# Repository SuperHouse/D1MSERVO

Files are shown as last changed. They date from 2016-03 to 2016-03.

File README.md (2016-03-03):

Servo Shield for the WeMos D1 Mini
==================================

Copyright 2016 SuperHouse Automation Pty Ltd  
SuperHouse site:  www.superhouse.tv  
SuperHouse email: info@superhouse.tv  

A 16-channel servo controller shield for the [WeMos D1 Mini][1] 
and other compatible boards based on the same header format.

Features:

 * 16 PWM output channels at 3.3V.
 * I2C interface with pull-up resistors.
 * Configurable I2C address to allow stacking. Default address 0x40.
 * PCA9685 PWM controller IC.
 * SCL: D1. SDA: D2.
 * External power terminals for powering servos at 6V.
 * Power jumper to link D1 Mini 5V rail to servo power.
 * OE (active low Output Enable) broken out for manual connection if required.
 * Power LED to show when servo power is available.

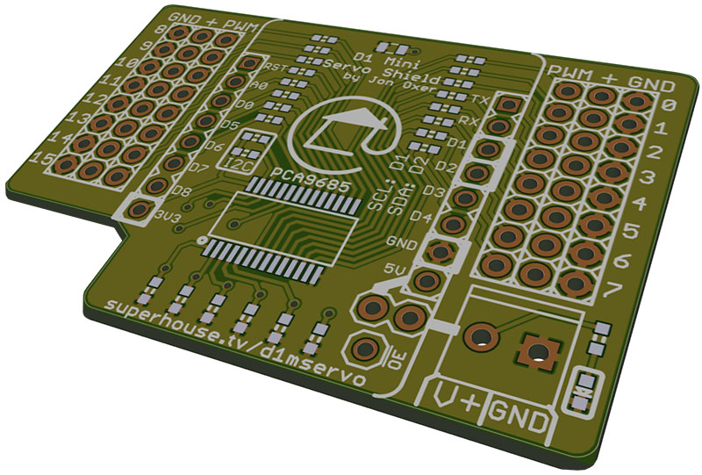
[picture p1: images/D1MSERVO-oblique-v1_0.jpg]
Oblique view


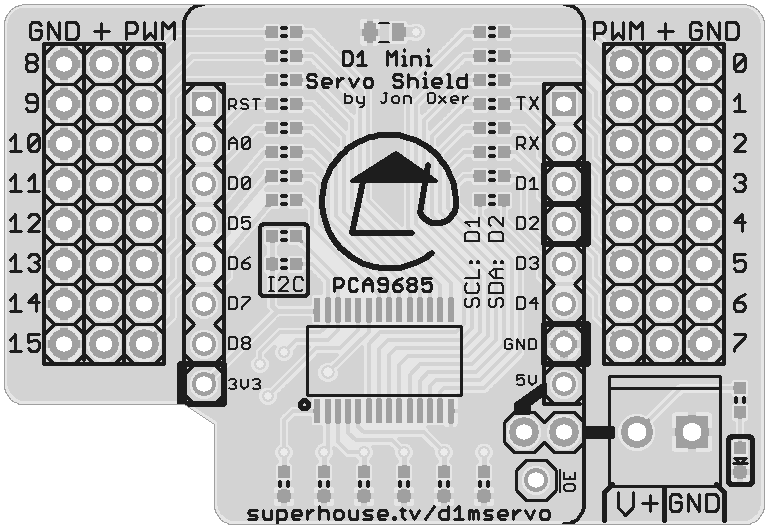
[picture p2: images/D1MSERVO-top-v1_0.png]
Top view


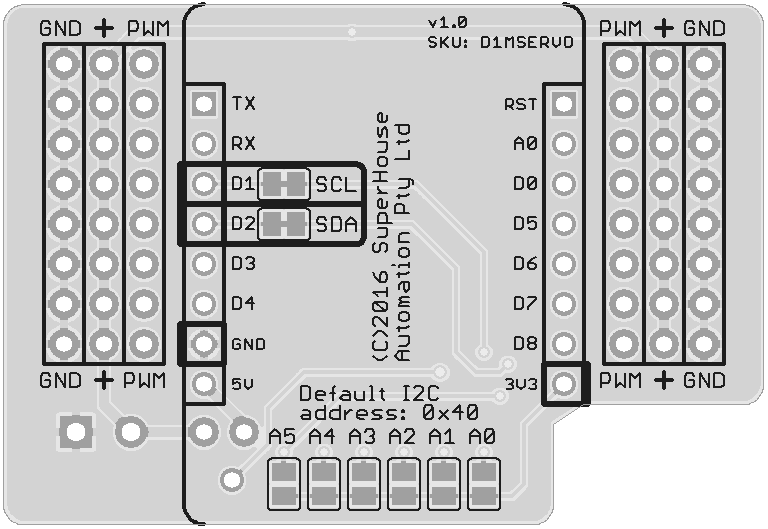
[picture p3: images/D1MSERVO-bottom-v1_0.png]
Bottom view


More information is available at:

  http://www.superhouse.tv/d1mservo

INSTALLATION
------------
The design is saved as an EAGLE project. EAGLE PCB design software is
available from www.cadsoftusa.com free for non-commercial use. To use
this project download it and place the directory containing these files
into the "eagle" directory on your computer.

DISTRIBUTION
------------
The specific terms of distribution of this project are governed by the
license referenced below.

LICENSE
-------
Licensed under the TAPR Open Hardware License (www.tapr.org/OHL).
The "license" folder within this repository also contains a copy of
this license in plain text format.

[1]: http://www.wemos.cc/wiki/doku.php?id=en:d1_mini

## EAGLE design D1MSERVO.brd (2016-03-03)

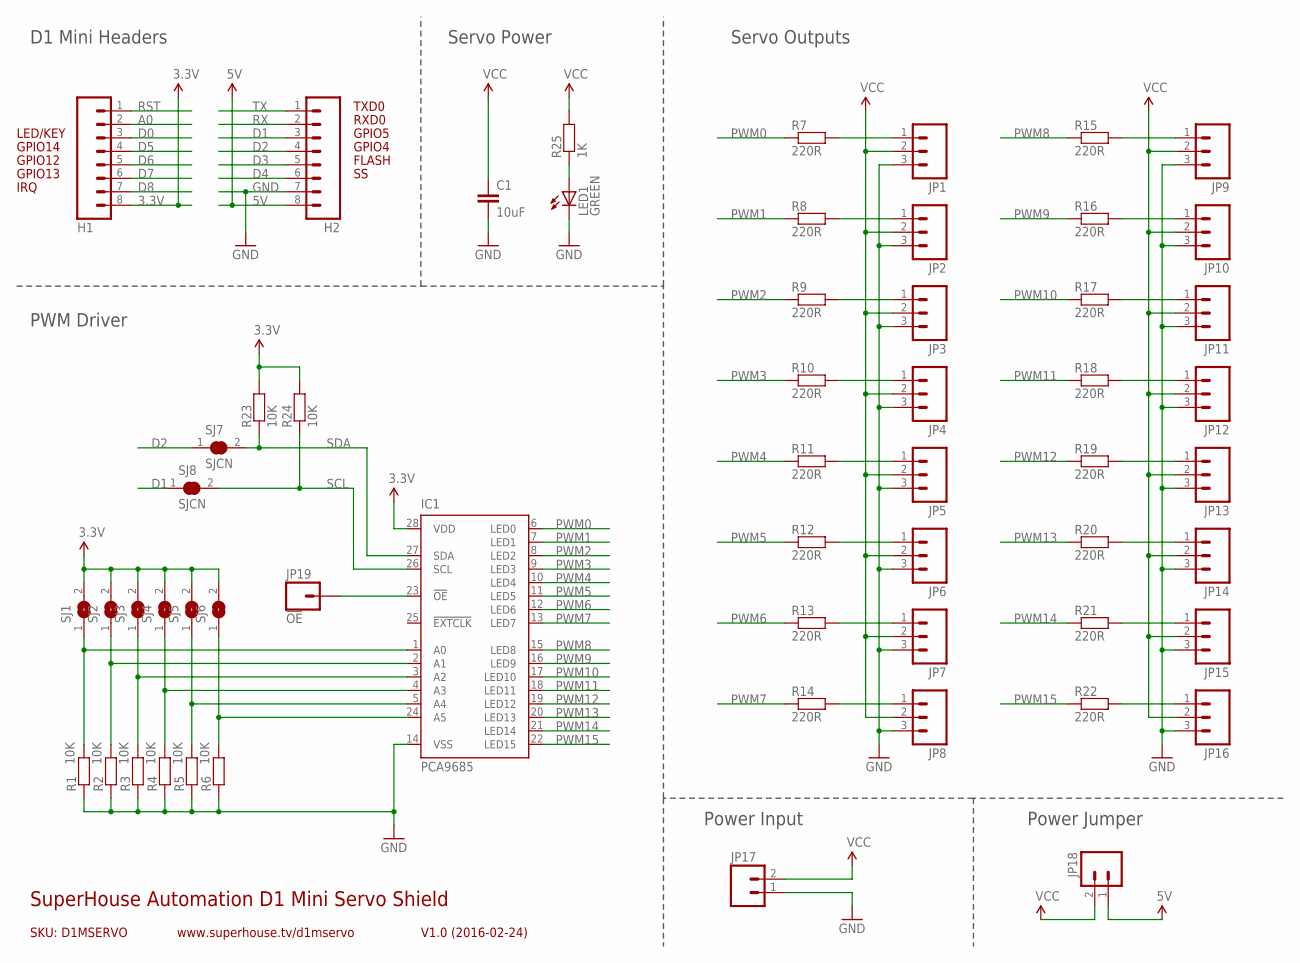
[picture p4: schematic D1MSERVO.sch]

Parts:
C1: 10uF; 0805
H1, H2: M08; 1X08
IC1: PCA9685; TSSOP28
JP1, JP2, JP3, JP4, JP5, JP6, JP7, JP8, JP9, JP10, JP11, JP12, JP13, JP14, JP15, JP16: M03PTH; 1X03
JP17: M023.5MM; SCREWTERMINAL-3.5MM-2
JP18: M02PTH; 1X02
JP19: !OE; 1X01
LED1: GREEN; LED-0603
R1, R2, R3, R4, R5, R6, R23, R24: 10K; 0603
R7, R8, R9, R10, R11, R12, R13, R14, R15, R16, R17, R18, R19, R20, R21, R22: 220R; 0603
R25: 1K; 0603
SJ1, SJ2, SJ3, SJ4, SJ5, SJ6: SJN; SJ
SJ7, SJ8: SJCN; SJC

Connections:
3.3V: H1.8, IC1.28 (VDD), R23.2, R24.2, SJ1.2, SJ2.2, SJ3.2, SJ4.2, SJ5.2, SJ6.2
5V: H2.8, JP18.1
A0: H1.2
D0: H1.3
D1: H2.3, SJ8.1
D2: H2.4, SJ7.1
D3: H2.5
D4: H2.6
D5: H1.4
D6: H1.5
D7: H1.6
D8: H1.7
GND: C1.2, H2.7, IC1.14 (VSS), JP1.3, JP2.3, JP3.3, JP4.3, JP5.3, JP6.3, JP7.3, JP8.3, JP9.3, JP10.3, JP11.3, JP12.3, JP13.3, JP14.3, JP15.3, JP16.3, JP17.1, LED1.C, R1.1, R2.1, R3.1, R4.1, R5.1, R6.1
unnamed: JP1.1, R7.2
unnamed: JP2.1, R8.2
unnamed: IC1.1 (A0), R1.2, SJ1.1
unnamed: IC1.2 (A1), R2.2, SJ2.1
unnamed: IC1.3 (A2), R3.2, SJ3.1
unnamed: IC1.4 (A3), R4.2, SJ4.1
unnamed: IC1.5 (A4), R5.2, SJ5.1
unnamed: IC1.24 (A5), R6.2, SJ6.1
unnamed: JP3.1, R9.2
unnamed: JP4.1, R10.2
unnamed: JP5.1, R11.2
unnamed: JP6.1, R12.2
unnamed: JP7.1, R13.2
unnamed: JP9.1, R15.2
unnamed: JP8.1, R14.2
unnamed: JP10.1, R16.2
unnamed: JP11.1, R17.2
unnamed: JP12.1, R18.2
unnamed: JP13.1, R19.2
unnamed: JP14.1, R20.2
unnamed: JP15.1, R21.2
unnamed: JP16.1, R22.2
unnamed: LED1.A, R25.1
unnamed: IC1.23 (!OE), JP19.1
PWM0: IC1.6 (LED0), R7.1
PWM1: IC1.7 (LED1), R8.1
PWM2: IC1.8 (LED2), R9.1
PWM3: IC1.9 (LED3), R10.1
PWM4: IC1.10 (LED4), R11.1
PWM5: IC1.11 (LED5), R12.1
PWM6: IC1.12 (LED6), R13.1
PWM7: IC1.13 (LED7), R14.1
PWM8: IC1.15 (LED8), R15.1
PWM9: IC1.16 (LED9), R16.1
PWM10: IC1.17 (LED10), R17.1
PWM11: IC1.18 (LED11), R18.1
PWM12: IC1.19 (LED12), R19.1
PWM13: IC1.20 (LED13), R20.1
PWM14: IC1.21 (LED14), R21.1
PWM15: IC1.22 (LED15), R22.1
RST: H1.1
RX: H2.2
SCL: IC1.26 (SCL), R24.1, SJ8.2
SDA: IC1.27 (SDA), R23.1, SJ7.2
TX: H2.1
VCC: C1.1, JP1.2, JP2.2, JP3.2, JP4.2, JP5.2, JP6.2, JP7.2, JP8.2, JP9.2, JP10.2, JP11.2, JP12.2, JP13.2, JP14.2, JP15.2, JP16.2, JP17.2, JP18.2, R25.2

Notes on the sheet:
FLASH
GPIO12
GPIO4
GPIO5
RXD0
TXD0
GPIO13
GPIO14
IRQ
LED/KEY
SKU: D1MSERVO
SuperHouse Automation D1 Mini Servo Shield
V1.0 (2016-02-24)
www.superhouse.tv/d1mservo
Servo Outputs
D1 Mini Headers
Power Input
PWM Driver
Power Jumper
Servo Power

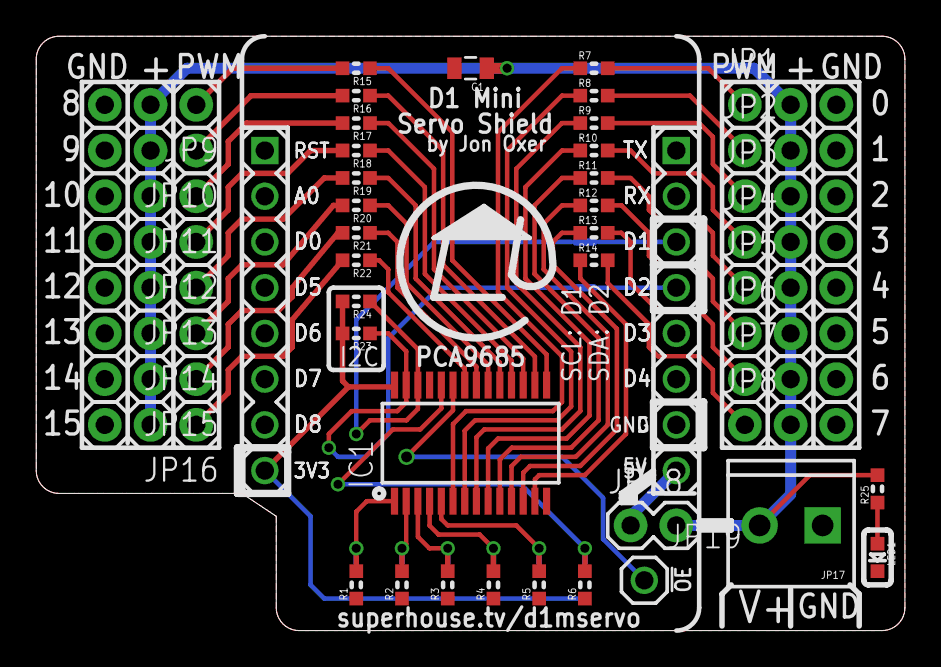
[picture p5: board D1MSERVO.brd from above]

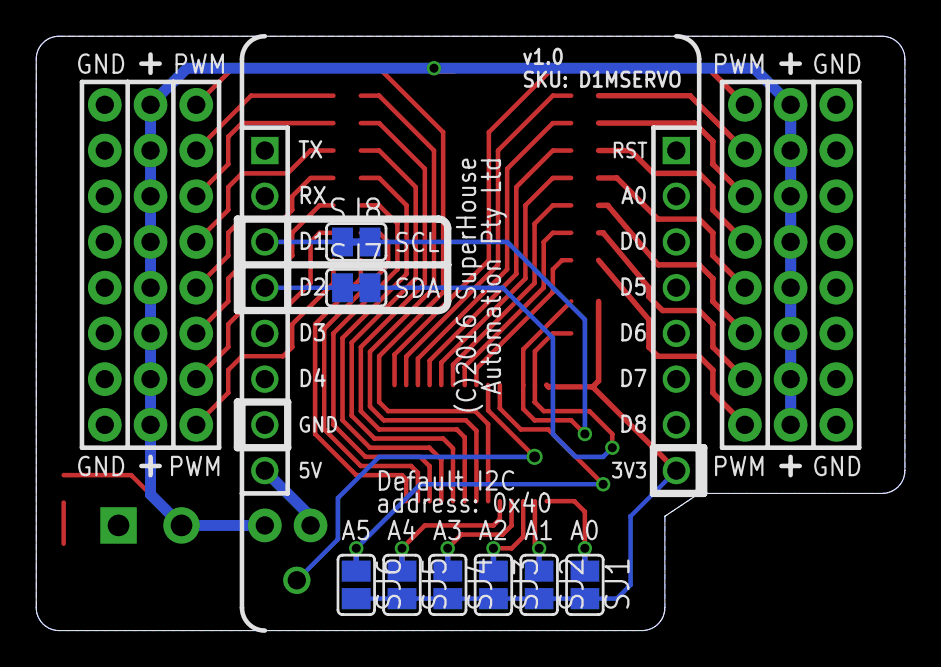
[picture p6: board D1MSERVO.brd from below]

Board: 2 copper layers, 48.3 x 33.0 mm, 57 parts (8 on the bottom side), 48 nets.

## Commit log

2016-02-26 Initial import
    [D1MSERVO.brd, D1MSERVO.sch]
2016-02-26 Changed I2C pins
    [D1MSERVO.brd, D1MSERVO.sch]
2016-02-29 Changed I2C pins (again) to match ESP12E like on the D1 Mini and D1 R2
    [D1MSERVO.brd, D1MSERVO.sch]
2016-03-03 Fixed silkscreen and preview images to reflect updated SCL and SDA pin assignments
    [D1MSERVO.brd]

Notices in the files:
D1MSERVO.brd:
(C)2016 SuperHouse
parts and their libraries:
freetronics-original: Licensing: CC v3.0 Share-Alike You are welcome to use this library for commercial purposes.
